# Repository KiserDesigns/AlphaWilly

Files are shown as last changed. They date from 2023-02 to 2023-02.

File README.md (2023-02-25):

Firmware built on this commit of Vial:

https://github.com/vial-kb/vial-qmk/commit/d4976853a3d72a370eeb24f6754e1618b5deb3bd

Newer Vial and QMK versions will need modification to firmware files.

PCB designed with Kicad 6.0.10, using various footprints and symbols with undetermined origin.

AlphaWetPCB/ is the Kicad PCB files

WilliamPlate/ is the Kicad Plate files

"William Plate.dxf" is the plate outline for laser cutting

alphawilly/ contains Vial and QMK firmware source

.uf2 file is the default firmware to flash.

GPL 3.0 License

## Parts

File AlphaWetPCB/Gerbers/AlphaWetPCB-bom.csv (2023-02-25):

Comment | Designator | Footprint | Quantity | JLCPCB Part #
SRV05-4 | U4 | SOT-23-6-routable | 1 | C85364
D_Small | D3,D28,D27,D2,D35,D24,D9,D4,D33,D12,D7,D13,D6,D8,D22,D23,D29,D18,D16,D5,D32,D10,D1,D25,D19,D15,D20,D30,D31,D11,D14,D17,D21,D34,D26 | D_SOD-123 | 35 | C81598
5.1k | R1,R3,R9 | R_0603_1608Metric | 3 | C23186
MX_SW_HS | SW6,SW1,SW9,SW16,SW26,SW5,SW10,SW24,SW23,SW13,SW43,SW11,SW2,SW27,SW25,SW12,SW7,SW19,SW22,SW3,SW18,SW28,SW8,SW14,SW20,SW15,SW4,SW42,SW41,SW17 | SW_MX_HS_1u | 30 | C2803348
100n | C11,C4,C10,C13,C8,C12,C9,C14,C7 | C_0402_1005Metric | 9 | C1525
500mA | F1 | Fuse_1206_3216Metric | 1 | C70077
-10k | R4 | R_0603_1608Metric | 1
XC6206PxxxMR | U1 | SOT-23 | 1 | C5446
1k | R8,R5 | R_0402_1005Metric | 2 | C11702
1u | C17,C18 | C_0402_1005Metric | 2 | C52923
10u | C15,C2,C1 | C_0402_1005Metric | 3 | C15525
USB_C_Receptacle_USB2.0 | J1 | USB_C_Receptacle_HRO_TYPE-C-31-M-12 | 1 | C165948
RP2040TR7 | U3 | QFN40P700X700X90-57N | 1 | C2040
MX_SW_HS | SW39,SW45 | SW_MX_HS_1.25u | 2 | C2803348
MX_SW_HS | SW40,SW44 | SW_MX_HS_1.75u | 2 | C2803348
MX_SW_HS | SW21,SW29 | SW_MX_HS_1.5u | 2 | C2803348
22 | R7,R6 | R_0402_1005Metric | 2 | C25092
SW_SPST | SWR1,SWR2 | SW_SPST_TL3342 | 2 | C318884
30p | C5,C6 | C_0402_1005Metric | 2 | C277479
W25Q128JVS | U2 | SOIC-8_5.23x5.23mm_P1.27mm | 1 | C97521
Crystal_GND24_Small | Y1 | Crystal_SMD_3225-4Pin_3.2x2.5mm | 1 | C9002

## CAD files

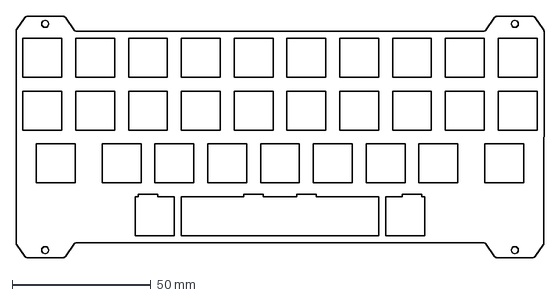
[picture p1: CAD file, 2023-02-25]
William Plate.dxf
190.5 x 87.1 mm

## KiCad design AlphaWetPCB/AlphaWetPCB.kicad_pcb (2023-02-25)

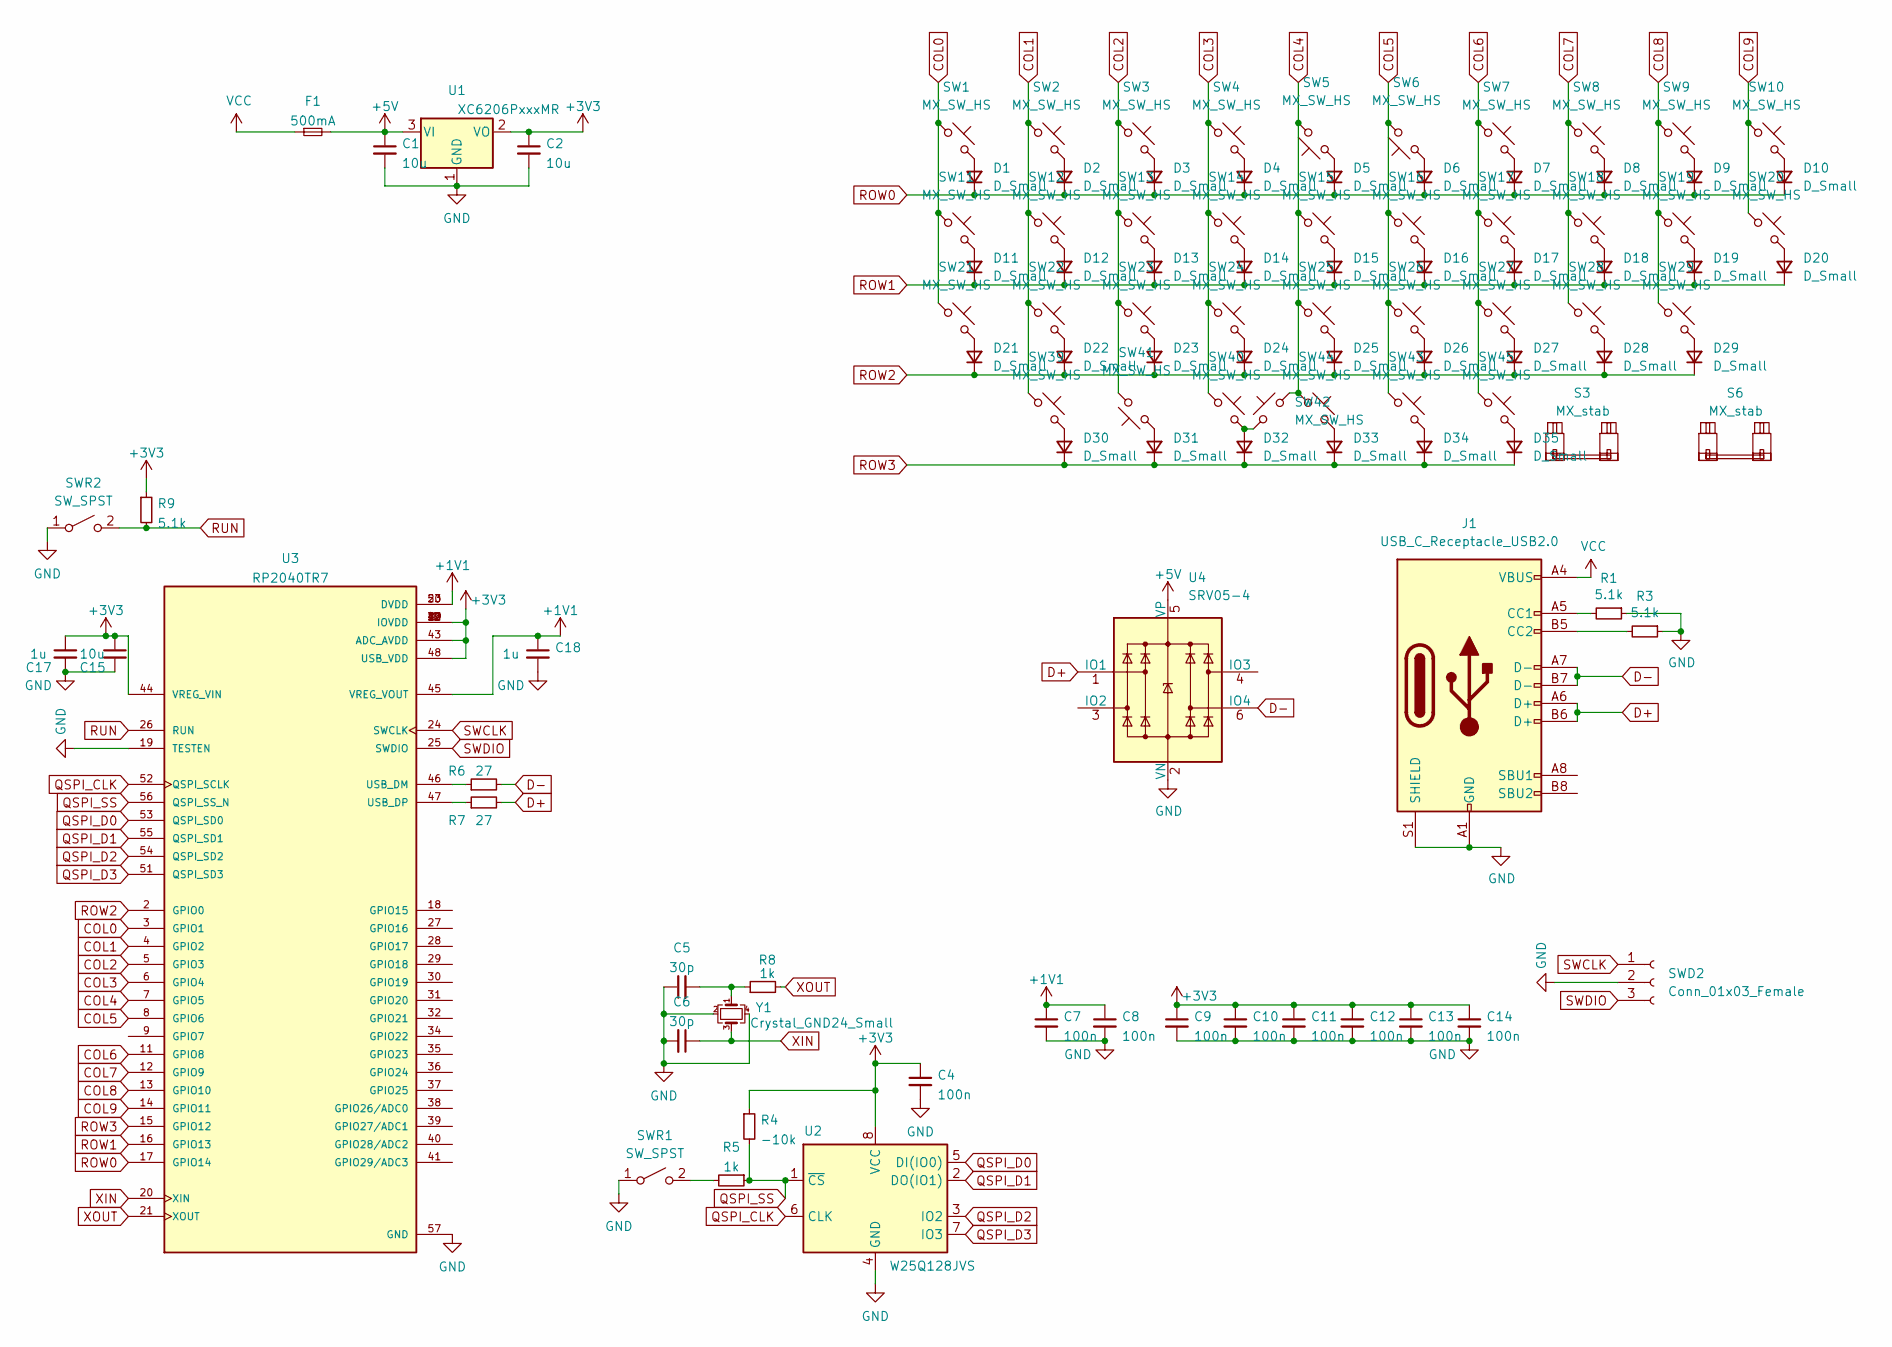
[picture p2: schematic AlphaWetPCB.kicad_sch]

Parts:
C1, C2, C15: 10u; C_0402_1005Metric
C4, C7, C8, C9, C10, C11, C12, C13, C14: 100n; C_0402_1005Metric
C5, C6: 30p; C_0402_1005Metric
C17, C18: 1u; C_0402_1005Metric
D1, D2, D3, D4, D5, D6, D7, D8, D9, D10, D11, D12, D13, D14, D15, D16, D17, D18, D19, D20, D21, D22, D23, D24, D25, D26, D27, D28, D29, D30, D31, D32, D33, D34, D35: D_Small; D_SOD-123
F1: 500mA; Fuse_1206_3216Metric
J1: USB_C_Receptacle_USB2.0; USB_C_Receptacle_HRO_TYPE-C-31-M-12
R1, R3: 5.1k; R_0603_1608Metric
R4: -10k; R_0603_1608Metric
R5, R8: 1k; R_0402_1005Metric
R6, R7: 27; R_0402_1005Metric
R9: 5.1k; R_0402_1005Metric
S3, S6: MX_stab; STAB_MX_3u
SW1, SW2, SW3, SW4, SW5, SW6, SW7, SW8, SW9, SW10, SW11, SW12, SW13, SW14, SW15, SW16, SW17, SW18, SW19, SW20, SW22, SW23, SW24, SW25, SW26, SW27, SW28, SW41, SW42, SW43: MX_SW_HS; SW_MX_HS_1u
SW21, SW29: MX_SW_HS; SW_MX_HS_1.5u
SW39, SW45: MX_SW_HS; SW_MX_HS_1.25u
SW40, SW44: MX_SW_HS; SW_MX_HS_1.75u
SWD2: Conn_01x03_Female; PinHeader_1x03_P2.54mm_Vertical
SWR1, SWR2: SW_SPST; SW_SPST_TL3342
U1: XC6206PxxxMR; SOT-23
U2: W25Q128JVS; SOIC-8_5.23x5.23mm_P1.27mm
U3: RP2040TR7; QFN40P700X700X90-57N; PARTREV 1.7.1
U4: SRV05-4; SOT-23-6-routable
Y1: Crystal_GND24_Small; Crystal_SMD_3225-4Pin_3.2x2.5mm

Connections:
+1V1: C7.1, C8.1, C18.1, U3.23 (DVDD), U3.45 (VREG_VOUT), U3.50 (DVDD)
+3V3: C2.1, C4.1, C9.1, C10.1, C11.1, C12.1, C13.1, C14.1, C15.1, C17.1, R4.1, R9.1, U1.2 (VO), U2.8 (VCC), U3.1 (IOVDD), U3.10 (IOVDD), U3.22 (IOVDD), U3.33 (IOVDD), U3.42 (IOVDD), U3.43 (ADC_AVDD), U3.44 (VREG_VIN), U3.48 (USB_VDD), U3.49 (IOVDD)
+5V: C1.1, F1.2, U1.3 (VI), U4.5 (VP)
COL0: SW1.1, SW11.1, SW21.1, U3.3 (GPIO1)
COL1: SW2.1, SW12.1, SW22.1, SW39.1, U3.4 (GPIO2)
COL2: SW3.1, SW13.1, SW23.1, SW41.2, U3.5 (GPIO3)
COL3: SW4.1, SW14.1, SW24.1, SW40.1, U3.6 (GPIO4)
COL4: SW5.2, SW15.1, SW25.1, SW42.2, SW44.1, U3.7 (GPIO5)
COL5: SW6.2, SW16.1, SW26.1, SW43.1, U3.8 (GPIO6)
COL6: SW7.1, SW17.1, SW27.1, SW45.1, U3.11 (GPIO8)
COL7: SW8.1, SW18.1, SW28.1, U3.12 (GPIO9)
COL8: SW9.1, SW19.1, SW29.1, U3.13 (GPIO10)
COL9: SW10.1, SW20.1, U3.14 (GPIO11)
D+: J1.A6 (D+), J1.B6 (D+), R7.2, U4.1 (IO1)
D-: J1.A7 (D-), J1.B7 (D-), R6.2, U4.6 (IO4)
GND: C1.2, C2.2, C4.2, C5.1, C6.2, C7.2, C8.2, C9.2, C10.2, C11.2, C12.2, C13.2, C14.2, C15.2, C17.2, C18.2, J1.A1 (GND), J1.A12 (GND), J1.B1 (GND), J1.B12 (GND), J1.S1 (SHIELD), R1.1, R3.1, SWD2.2, SWR1.1 (A), SWR2.1 (A), U1.1 (GND), U2.4 (GND), U3.19 (TESTEN), U3.57 (GND), U4.2 (VN), Y1.2, Y1.4
unnamed: C5.2, R8.1, Y1.1
unnamed: D1.2 (A), SW1.2
unnamed: D2.2 (A), SW2.2
unnamed: D3.2 (A), SW3.2
unnamed: D4.2 (A), SW4.2
unnamed: D5.2 (A), SW5.1
unnamed: D6.2 (A), SW6.1
unnamed: D7.2 (A), SW7.2
unnamed: D8.2 (A), SW8.2
unnamed: D9.2 (A), SW9.2
unnamed: D10.2 (A), SW10.2
unnamed: D11.2 (A), SW11.2
unnamed: D12.2 (A), SW12.2
unnamed: D13.2 (A), SW13.2
unnamed: D14.2 (A), SW14.2
unnamed: D15.2 (A), SW15.2
unnamed: D16.2 (A), SW16.2
unnamed: D17.2 (A), SW17.2
unnamed: D18.2 (A), SW18.2
unnamed: D19.2 (A), SW19.2
unnamed: D20.2 (A), SW20.2
unnamed: D21.2 (A), SW21.2
unnamed: D22.2 (A), SW22.2
unnamed: D23.2 (A), SW23.2
unnamed: D24.2 (A), SW24.2
unnamed: D25.2 (A), SW25.2
unnamed: D26.2 (A), SW26.2
unnamed: D27.2 (A), SW27.2
unnamed: D28.2 (A), SW28.2
unnamed: D29.2 (A), SW29.2
unnamed: D30.2 (A), SW39.2
unnamed: D31.2 (A), SW41.1
unnamed: D32.2 (A), SW40.2, SW42.1
unnamed: D33.2 (A), SW44.2
unnamed: D34.2 (A), SW43.2
unnamed: D35.2 (A), SW45.2
unnamed: J1.A5 (CC1), R1.2
unnamed: J1.B5 (CC2), R3.2
unnamed: R5.2, SWR1.2 (B)
unnamed: R6.1, U3.46 (USB_DM)
unnamed: R7.1, U3.47 (USB_DP)
QSPI_CLK: U2.6 (CLK), U3.52 (QSPI_SCLK)
QSPI_D0: U2.5 (DI(IO0)), U3.53 (QSPI_SD0)
QSPI_D1: U2.2 (DO(IO1)), U3.55 (QSPI_SD1)
QSPI_D2: U2.3 (IO2), U3.54 (QSPI_SD2)
QSPI_D3: U2.7 (IO3), U3.51 (QSPI_SD3)
QSPI_SS: R4.2, R5.1, U2.1 (~CS), U3.56 (QSPI_SS_N)
ROW0: D1.1 (K), D2.1 (K), D3.1 (K), D4.1 (K), D5.1 (K), D6.1 (K), D7.1 (K), D8.1 (K), D9.1 (K), D10.1 (K), U3.17 (GPIO14)
ROW1: D11.1 (K), D12.1 (K), D13.1 (K), D14.1 (K), D15.1 (K), D16.1 (K), D17.1 (K), D18.1 (K), D19.1 (K), D20.1 (K), U3.16 (GPIO13)
ROW2: D21.1 (K), D22.1 (K), D23.1 (K), D24.1 (K), D25.1 (K), D26.1 (K), D27.1 (K), D28.1 (K), D29.1 (K), U3.2 (GPIO0)
ROW3: D30.1 (K), D31.1 (K), D32.1 (K), D33.1 (K), D34.1 (K), D35.1 (K), U3.15 (GPIO12)
RUN: R9.2, SWR2.2 (B), U3.26 (RUN)
SWCLK: SWD2.1, U3.24 (SWCLK)
SWDIO: SWD2.3, U3.25 (SWDIO)
VCC: F1.1, J1.A4 (VBUS), J1.A9 (VBUS), J1.B4 (VBUS), J1.B9 (VBUS)
XIN: C6.1, U3.20 (XIN), Y1.3
XOUT: R8.2, U3.21 (XOUT)

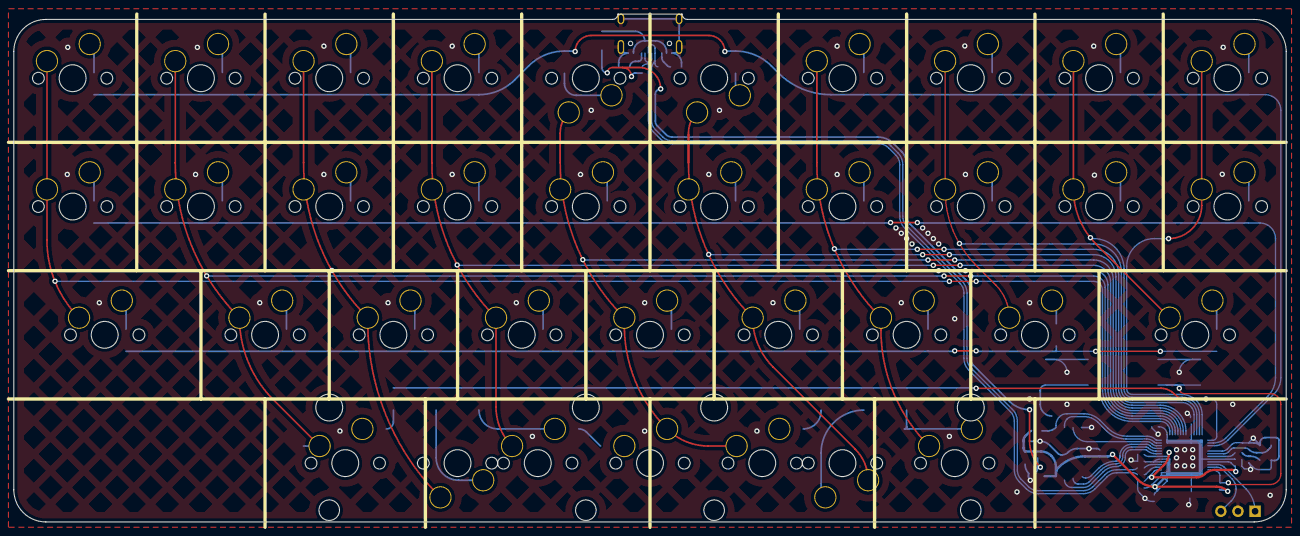
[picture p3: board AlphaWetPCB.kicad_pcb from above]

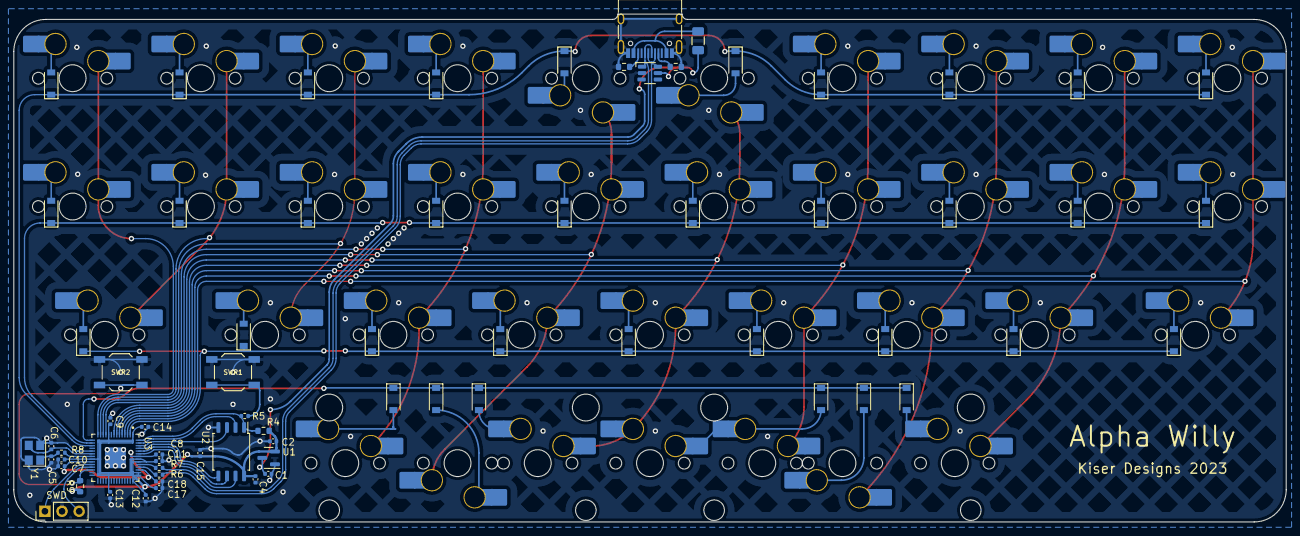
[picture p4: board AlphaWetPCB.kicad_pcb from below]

Board: 2 copper layers, 188.9 x 75.4 mm, 107 parts (105 on the bottom side), 73 nets.

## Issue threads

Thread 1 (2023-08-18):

Error when attempting to compile new QMK firmware

arrowtype, 2023-08-18:
Hey, I'm loving my new AlphaWilly, but I'm trying to compile new vial firmware so I can:
- Use the latest QMK settings for mod-tap behavior
- Add an additional layer to vial (for fn keys)

I think I've gotten allllmost there, but I'm getting stuck. So far, I have done the following:

1. Pulled the latest from the upstream QMK repo into my local QMK repo (fetch and merge)
2. Run `make git-submodule` to update dependencies
3. Added `keyboards/alphawilly` from the folder in this repo, then added and additional layer to `keyboards/alphawilly/keymaps/vial/keymap.c` ([permalink](https://github.com/arrowtype/qmk_firmware/blob/18eaa0aec758647961809adfcbf13832d9428ac2/keyboards/alphawilly/keymaps/vial/keymap.c))
4. Added a line to config.h based on an error suggestion `#define DYNAMIC_KEYMAP_LAYER_COUNT 5` ([permalink](https://github.com/arrowtype/qmk_firmware/blob/master/keyboards/alphawilly/keymaps/vial/config.h))

But, now I'm getting a more complex error, and I'm hoping someone might be able to suggest what the next step would be. Here's my current build traceback:

```
~/code/qmk_firmware  master ✗                                                                                                                                                                                        6m ⚑  ⍉
▶ qmk compile -kb alphawilly -km vial
Ψ Compiling keymap with gmake --jobs=1 alphawilly:vial

QMK Firmware 0.21.6
⚠ alphawilly: DEVICE_VER in config.h is deprecated in favor of `usb.device_version` in info.json and will be removed at a later date
⚠ alphawilly: MANUFACTURER in config.h is deprecated in favor of `manufacturer` in info.json and will be removed at a later date
⚠ alphawilly: PRODUCT in config.h is deprecated in favor of `keyboard_name` in info.json and will be removed at a later date
⚠ alphawilly: PRODUCT_ID in config.h is deprecated in favor of `usb.pid` in info.json and will be removed at a later date
⚠ alphawilly: VENDOR_ID in config.h is deprecated in favor of `usb.vid` in info.json and will be removed at a later date
☒ alphawilly: No LAYOUTs defined! Need at least one layout defined in info.json.
Making alphawilly with keymap vial

⚠ alphawilly: DEVICE_VER in config.h is deprecated in favor of `usb.device_version` in info.json and will be removed at a later date
⚠ alphawilly: MANUFACTURER in config.h is deprecated in favor of `manufacturer` in info.json and will be removed at a later date
⚠ alphawilly: PRODUCT in config.h is deprecated in favor of `keyboard_name` in info.json and will be removed at a later date
⚠ alphawilly: PRODUCT_ID in config.h is deprecated in favor of `usb.pid` in info.json and will be removed at a later date
⚠ alphawilly: VENDOR_ID in config.h is deprecated in favor of `usb.vid` in info.json and will be removed at a later date
☒ alphawilly: No LAYOUTs defined! Need at least one layout defined in info.json.
arm-none-eabi-gcc (GNU Tools for Arm Embedded Processors 8-2019-q3-update) 8.3.1 20190703 (release) [gcc-8-branch revision 273027]
Copyright (C) 2018 Free Software Foundation, Inc.
This is free software; see the source for copying conditions.  There is NO
warranty; not even for MERCHANTABILITY or FITNESS FOR A PARTICULAR PURPOSE.

Compiling: keyboards/alphawilly/alphawilly.c                                                        [OK]
Compiling: .build/obj_alphawilly/src/default_keyboard.c                                             [OK]
Compiling: quantum/keymap_introspection.c                                                           [OK]
Compiling: quantum/quantum.c                                                                        [OK]
Compiling: quantum/bitwise.c                                                                        [OK]
Compiling: quantum/led.c                                                                            [OK]
Compiling: quantum/action.c                                                                         [OK]
Compiling: quantum/action_layer.c                                                                   [OK]
Compiling: quantum/action_tapping.c                                                                 [OK]
Compiling: quantum/action_util.c                                                                    [OK]
Compiling: quantum/eeconfig.c                                                                       [OK]
Compiling: quantum/keyboard.c                                                                       [OK]
Compiling: quantum/keymap_common.c                                                                  [OK]
Compiling: quantum/keycode_config.c                                                                 [OK]
Compiling: quantum/sync_timer.c                                                                     [OK]
Compiling: quantum/logging/debug.c                                                                  [OK]
Compiling: quantum/logging/sendchar.c                                                               [OK]
Compiling: quantum/logging/print.c                                                                  [OK]
Compiling: quantum/bootmagic/bootmagic_lite.c                                                       [OK]
Compiling: quantum/bootmagic/magic.c                                                                [OK]
Compiling: quantum/matrix_common.c                                                                  [OK]
Compiling: quantum/matrix.c                                                                         [OK]
Compiling: quantum/debounce/sym_defer_g.c                                                           [OK]
Compiling: quantum/main.c                                                                           [OK]
Compiling: lib/printf/src/printf/printf.c                                                           [OK]
Compiling: quantum/mousekey.c                                                                       [OK]
Compiling: drivers/eeprom/eeprom_driver.c                                                           [OK]
Compiling: drivers/eeprom/eeprom_wear_leveling.c                                                    [OK]
Compiling: quantum/wear_leveling/wear_leveling.c                                                    [OK]
Compiling: platforms/chibios/drivers/wear_leveling/wear_leveling_rp2040_flash.c                     [OK]
Compiling: quantum/via.c                                                                            [OK]
Compiling: lib/fnv/qmk_fnv_type_validation.c                                                        [OK]
Compiling: lib/fnv/hash_32a.c                                                                       [OK]
Compiling: lib/fnv/hash_64a.c                                                                       [OK]
Compiling: quantum/process_keycode/process_magic.c                                                  [OK]
Compiling: quantum/send_string/send_string.c                                                        [OK]
Compiling: quantum/dynamic_keymap.c                                                                 [OK]
Compiling: quantum/process_keycode/process_grave_esc.c                                              [OK]
Compiling: quantum/process_keycode/process_space_cadet.c                                            [OK]
Compiling: quantum/process_keycode/process_tap_dance.c                                              [OK]
Compiling: quantum/process_keycode/process_tri_layer.c                                              [OK]
Compiling: quantum/tri_layer.c                                                                      [OK]
Assembling: lib/chibios/os/common/startup/ARMCMx/compilers/GCC/crt0_v6m.S                           [OK]
Assembling: lib/chibios/os/common/startup/ARMCMx/compilers/GCC/vectors.S                            [OK]
Assembling: lib/chibios/os/common/ports/ARMv6-M-RP2/compilers/GCC/chcoreasm.S                       [OK]
Compiling: tmk_core/protocol/host.c                                                                 [OK]
Compiling: tmk_core/protocol/report.c                                                               [OK]
Compiling: tmk_core/protocol/usb_device_state.c                                                     [OK]
Compiling: tmk_core/protocol/usb_util.c                                                             [OK]
Compiling: platforms/suspend.c                                                                      [OK]
Compiling: platforms/synchronization_util.c                                                         [OK]
Compiling: platforms/timer.c                                                                        [OK]
Compiling: platforms/chibios/hardware_id.c                                                          [OK]
Compiling: platforms/chibios/platform.c                                                             [OK]
Compiling: platforms/chibios/suspend.c                                                              [OK]
Compiling: platforms/chibios/timer.c                                                                [OK]
Compiling: platforms/chibios/bootloaders/rp2040.c                                                   [OK]
Compiling: tmk_core/protocol/chibios/usb_main.c                                                     [OK]
Compiling: tmk_core/protocol/chibios/chibios.c                                                      [OK]
Compiling: tmk_core/protocol/usb_descriptor.c                                                      In file included from tmk_core/protocol/usb_descriptor.c:42:
tmk_core/protocol/usb_descriptor_common.h:21:29: error: 'LKiser' undeclared here (not in a function)
 #define USBSTR(s) USBCONCAT(L, s)
                             ^
tmk_core/protocol/usb_descriptor_common.h:20:25: note: in definition of macro 'USBCONCAT'
 #define USBCONCAT(a, b) a##b
                         ^
tmk_core/protocol/usb_descriptor.c:1066:42: note: in expansion of macro 'USBSTR'
         .Size                   = sizeof(USBSTR(MANUFACTURER)),
                                          ^~~~~~
./keyboards/alphawilly/config.h:15:31: error: expected ')' before 'Designs'
 #define MANUFACTURER    Kiser Designs
                               ^~~~~~~
tmk_core/protocol/usb_descriptor_common.h:20:28: note: in definition of macro 'USBCONCAT'
 #define USBCONCAT(a, b) a##b
                            ^
tmk_core/protocol/usb_descriptor.c:1066:42: note: in expansion of macro 'USBSTR'
         .Size                   = sizeof(USBSTR(MANUFACTURER)),
                                          ^~~~~~
tmk_core/protocol/usb_descriptor.c:1066:49: note: in expansion of macro 'MANUFACTURER'
         .Size                   = sizeof(USBSTR(MANUFACTURER)),
                                                 ^~~~~~~~~~~~
tmk_core/protocol/usb_descriptor.c:1066:41: note: to match this '('
         .Size                   = sizeof(USBSTR(MANUFACTURER)),
                                         ^
In file included from tmk_core/protocol/usb_descriptor.c:42:
./keyboards/alphawilly/config.h:15:31: error: expected '}' before 'Designs'
 #define MANUFACTURER    Kiser Designs
                               ^~~~~~~
tmk_core/protocol/usb_descriptor_common.h:20:28: note: in definition of macro 'USBCONCAT'
 #define USBCONCAT(a, b) a##b
                            ^
tmk_core/protocol/usb_descriptor.c:1069:35: note: in expansion of macro 'USBSTR'
     .UnicodeString              = USBSTR(MANUFACTURER)
                                   ^~~~~~
tmk_core/protocol/usb_descriptor.c:1069:42: note: in expansion of macro 'MANUFACTURER'
     .UnicodeString              = USBSTR(MANUFACTURER)
                                          ^~~~~~~~~~~~
tmk_core/protocol/usb_descriptor.c:1064:60: note: to match this '{'
 const USB_Descriptor_String_t PROGMEM ManufacturerString = {
                                                            ^
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
